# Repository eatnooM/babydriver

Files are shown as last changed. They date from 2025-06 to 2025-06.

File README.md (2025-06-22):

# babydriver

A small but capable force feedback board for use with GUN4IR and OpenFIRE light guns.

License: CC BY-SA 4.0

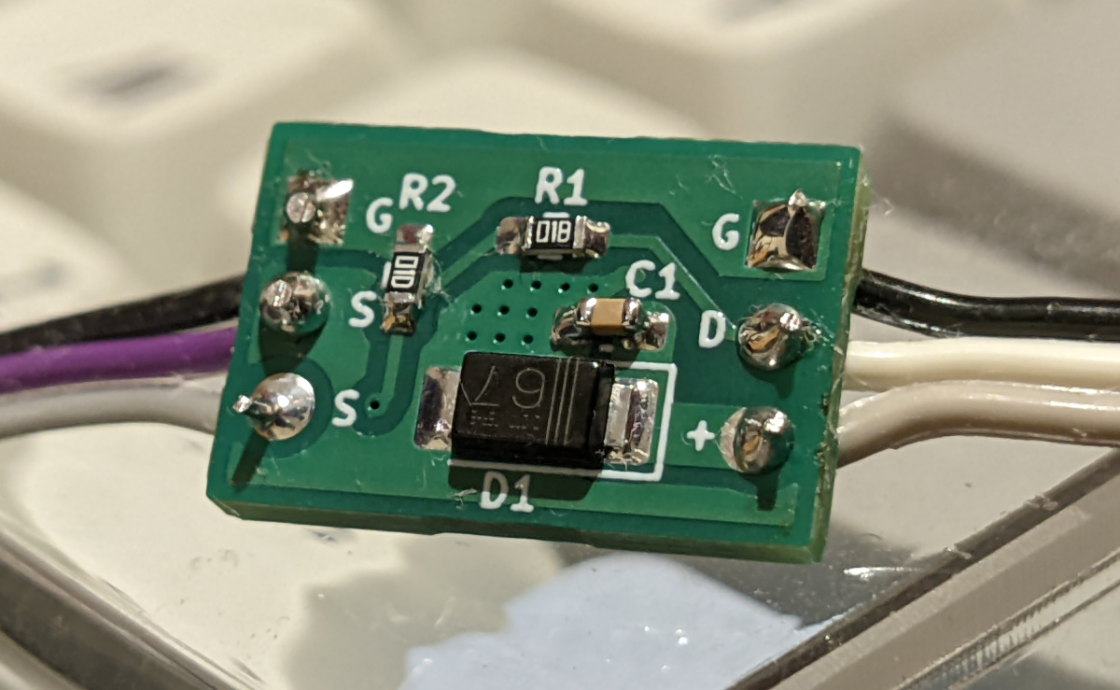
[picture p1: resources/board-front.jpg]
Image of assembled PCB from front

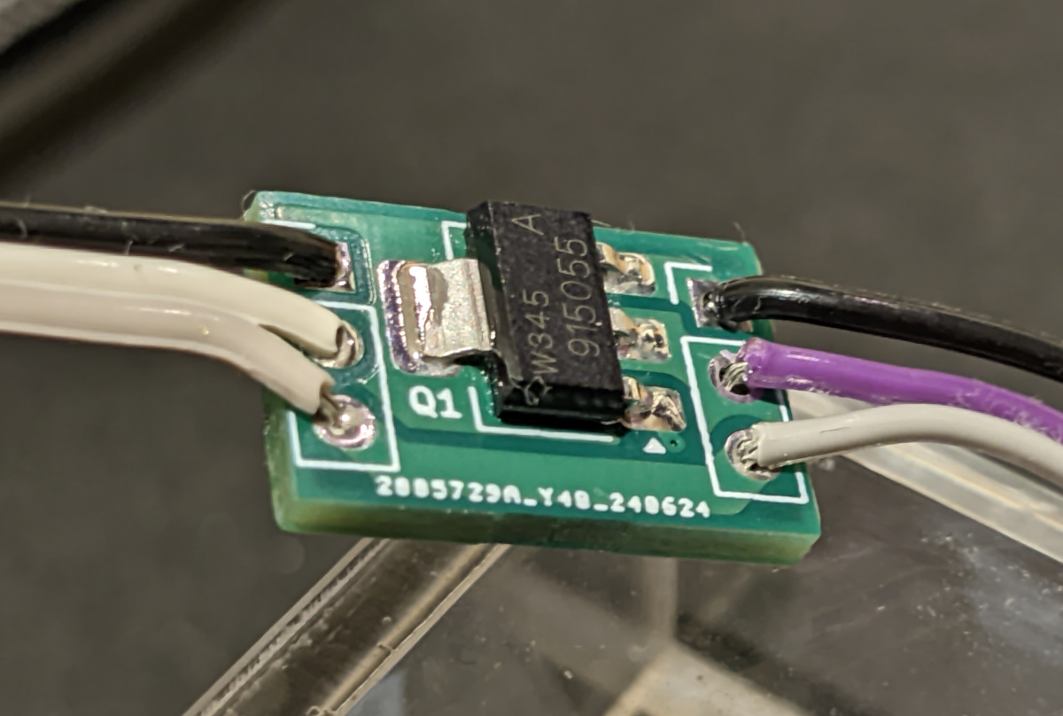
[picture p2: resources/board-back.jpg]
Image of assembled PCB from back


## BOM

| Reference | Part desc / number | Notes |
|---|---|---|
| Q1 | BUK98150-55A - [Mouser](https://www.mouser.com/ProductDetail/Nexperia/BUK98150-55A-CUF?qs=Yna0arPQ0CRUeN6OsRm%252BFA%3D%3D) / [LCSC](https://lcsc.com/product-detail/MOSFETs_Nexperia-BUK98150-55A-CUF_C458219.html) |  |
| D1 | RF201LAM2STR  - [Mouser](https://www.mouser.co.uk/ProductDetail/ROHM-Semiconductor/RF202LAM2STFTR?qs=HXFqYaX1Q2zHR%252BhwlkXHhw%3D%3D) / [LCSC](https://lcsc.com/product-detail/Fast-Recovery-High-Efficiency-Diodes_ROHM-Semicon-RF202LAM2STFTR_C5336592.html) | RF202LAM2S or RF302LAM2S will work fine too|
| C1 | 0.1uF - [Mouser](https://www.mouser.co.uk/ProductDetail/YAGEO/CC0603KRX7R9BB104?qs=vTakOoo5QyLvVCYM2ge8LQ%3D%3D) / [LCSC](https://www.lcsc.com/product-detail/_YAGEO-_C14663.html) |
| R1 | 1K 0603 - [Mouser](https://www.mouser.co.uk/ProductDetail/YAGEO/RC0603FR-071KL?qs=VU8sRB4EgwApHsk4rF%2F3zg%3D%3D) / [LCSC](https://lcsc.com/product-detail/Chip-Resistor-Surface-Mount_YAGEO-RC0603FR-071KL_C22548.html) | |
| R2 | 100K 0603 - [Mouser](https://www.mouser.co.uk/ProductDetail/YAGEO/RC0603FR-07100KL?qs=e1ok2LiJcmaihem8Va5%2Fsw%3D%3D) / [LCSC](https://lcsc.com/product-detail/Chip-Resistor-Surface-Mount_YAGEO-RC0603FR-07100KL_C14675.html) |  |

## Ordering

Grab the gerbers and upload to your preferred fab, or use the shared project links: [OSHPark](https://oshpark.com/shared_projects/hxcLf80E) / [PCBWay](https://www.pcbway.com/project/shareproject/babydriver_2d900780.html)

## Assembly

Considering the board is roughly the size of an SD card, the design uses 4 layers to increase thermal mass and keep the MOSFET cool during operation.
There are also no thermal reliefs due to these space constraints, so be prepared for the board to sink some heat while soldering!

Simply solder all components (watch the polarity on the diode!) and wire (looking at the side of the board with the labels):

Left side:
- G: Ground - Microcontroller ground
- S: Solenoid / rumble motor (polarity typically doesn't matter but the outer hole is positive, while the middle pad is GND when the MOSFET is active)

Right side (input):
- G: Ground - external power supply ground (can be omitted if not using an external power supply)
- D: Data pin to activate rumble / solenoid
- +: Power for force feedback
    - For solenoid, this will be the +12/+24V from your external power supply
	- For most rumble setups, this can be wired to the 3.3/5V on your microcontroller, depending on the voltage rating and power draw of the motor.

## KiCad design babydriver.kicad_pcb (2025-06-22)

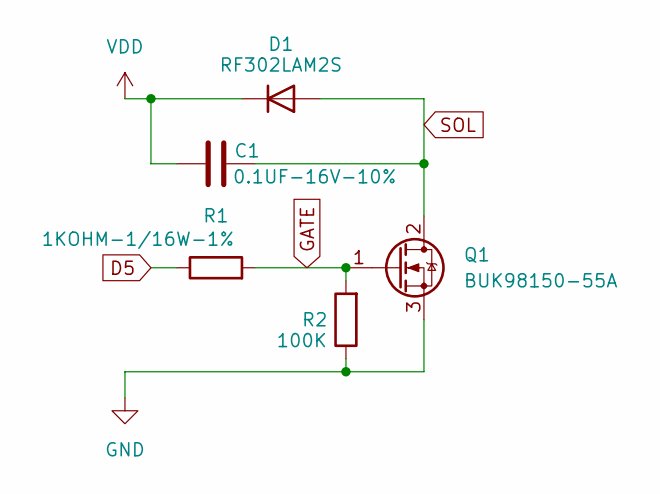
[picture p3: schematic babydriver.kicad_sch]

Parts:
C1: 0.1UF-16V-10%; C_0603_1608Metric_Pad1.08x0.95mm_HandSolder
D1: RF302LAM2S; D_SOD-128
Q1: BUK98150-55A; SOT-223-3_TabPin2
R1: 1KOHM-1/16W-1%; R_0603_1608Metric_Pad0.98x0.95mm_HandSolder
R2: 100K; R_0603_1608Metric_Pad0.98x0.95mm_HandSolder

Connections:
D5: R1.1
GATE: Q1.1 (G), R1.2, R2.2
GND: Q1.3 (S), R2.1
SOL: C1.1, D1.2 (A), Q1.2 (D)
VDD: C1.2, D1.1 (K)

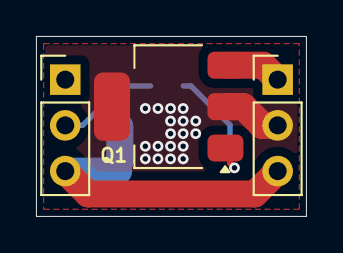
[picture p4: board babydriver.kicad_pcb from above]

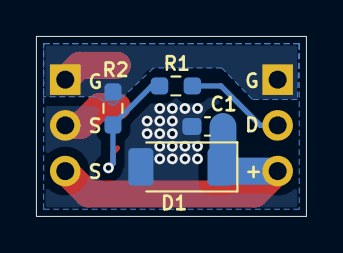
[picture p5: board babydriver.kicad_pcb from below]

Board: 4 copper layers, 15.0 x 10.0 mm, 5 parts (4 on the bottom side), 4 nets.

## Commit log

2025-06-22 Add project files and license
    [babydriver.kicad_pcb, babydriver.kicad_sch]
2025-06-22 Add pictures of both sides of board
